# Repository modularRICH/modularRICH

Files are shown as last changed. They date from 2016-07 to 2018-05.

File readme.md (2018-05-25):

# Modular Ring Imaging Cherenkov Particle Identification Detector
The modular aerogel RICH is designed for hadron identification covering a momentum range of 3-10 GeV/c. Identification of the hadrons in the final state is needed for understanding how different quark flavors contribute to the properties of hadrons, and reliable identification of the scattered electron is important for covering kinematics where pion backgrounds are large. This hardware is being prototyped as one of the detectors in the future [Electron-Ion Collider](https://arxiv.org/abs/1212.1701) (EIC), and some of them have recently been tested at Fermilab.

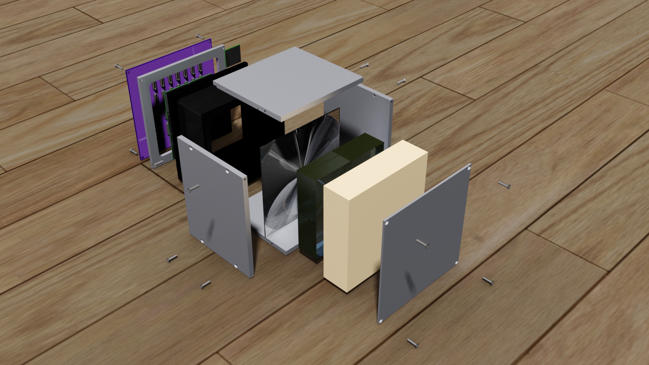
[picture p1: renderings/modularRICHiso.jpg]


## Theory
Aerogel, silicon dioxide and air has a very low index of refraction, and is being used as a radiator material. When high energy charged particles, the remnants of collisions in the interaction region, pass through the aerogel, their phase velocity exceeds that of the speed of light in the medium. They release some of this energy in the form of cones of light, emanating from the collision point. The particle continues through, generally passing through the rest of the instrument.

This cone of light then passes through the Fresnel lens where it is focused towards the center of the sensor plane, which lies at the focal length. The mirrors provide light from particles coming in at an angle to still be focused on the sensor. The ring pattern that emerges can be able to differentiate pions and kaons, and their respective energies.

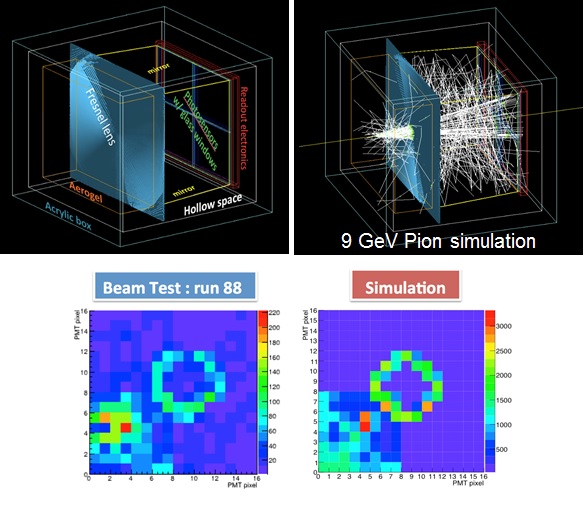
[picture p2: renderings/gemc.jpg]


## Hardware
The detector consists of a optical cavity that is sealed to be light tight, and a interface board for electronics, that allows the heat to be dissipated. The modules in the prototype are designed to be easily removable allowing runs with and without the mirror, aerogel, and/or lens and servicing. The list follows the beam path.

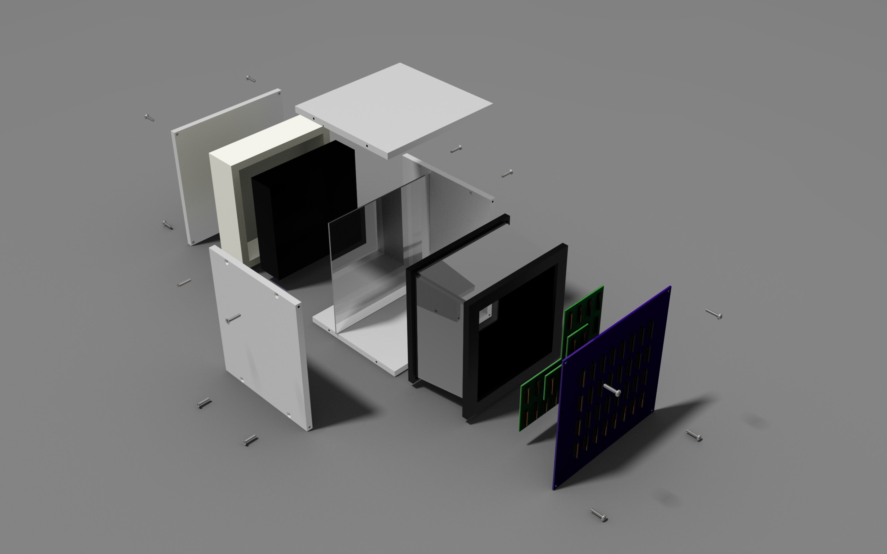
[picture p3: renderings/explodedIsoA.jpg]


### Frame
The frame is made from 1/4" aluminium and assembled with 4-40 screws. The rabet joints form blind corners, which can be further sealed with RTV or aluminium tape. The metal sides are much better at blocking light than the acrylic used in the earlier prototype that was less opaque than expected. The interior and exterior are anodized black to prevent internal light bounces to blur the image. The top and bottom sections are grooved allowing precise placements of the inner modules, and prevent them from shifting. Any of the five panels can be easily removed with only four screws, making servicing quick.

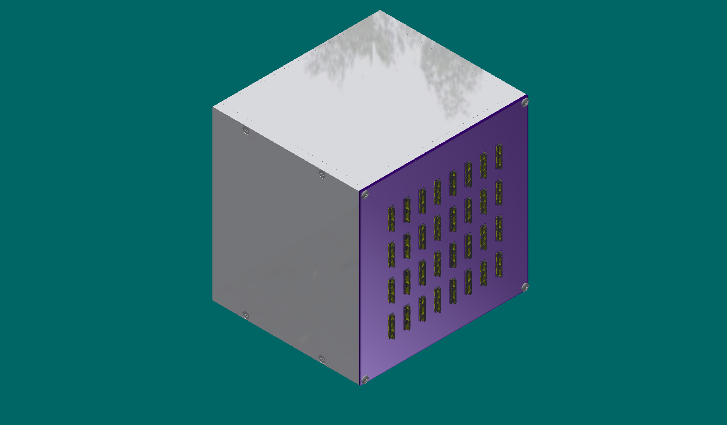
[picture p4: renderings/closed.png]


### Aerogel
Silica aerogel has been used for decades in threshold Cherenkov counters for high energy physics. The aerogel block used is 110mm x 110mm x 33mm and housed in a foam block. The material is extremely fragile and fractures irregular based on formation impurities. It has a index of refraction around 1.01-1.10 depending on its quality, and may have a slight blue hue or be completely clear.

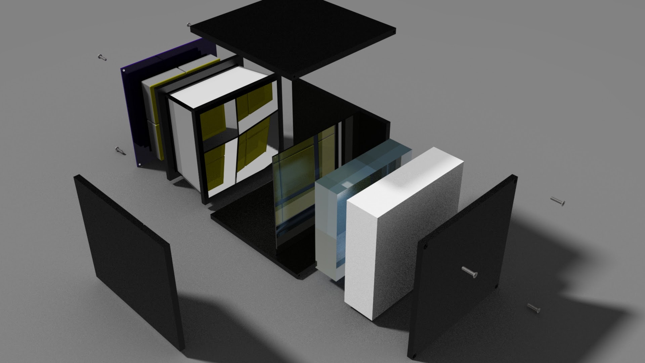
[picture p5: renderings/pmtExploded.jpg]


### Fresnel Lens
The fresnel lens used in this design is manufactured by Edmond Optics [part#](http://www.edmundoptics.com/optics/optical-lenses/fresnel-lenses/fresnel-lenses) and has the critical dimension of 6in for the focal length. It is cut smaller than its original 6.7in x 6.7in (fix size) on order to fit the box, and has an effective diameter of 6in. Due to those two factors, the edges of the lens do not contain any grooves, and are ineffective at refracting light. By switching to a longer focal length lens than our previous prototype (3in), we are able to get a larger ring size, and therefore increse the identification power. 

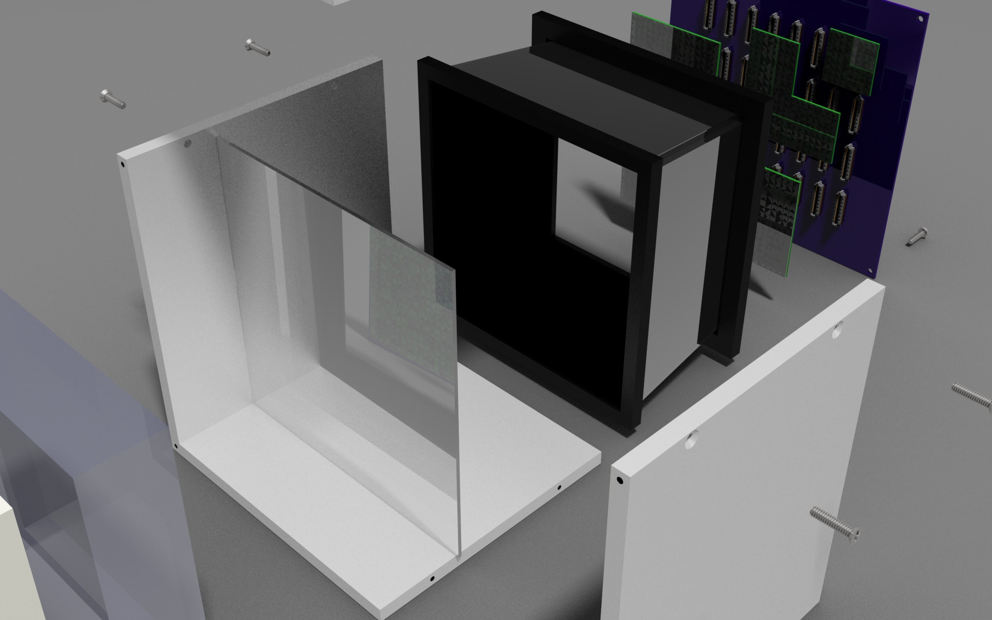
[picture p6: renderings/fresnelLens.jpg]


### Mirror
The mirrors used are front surface mirrors that are trapezoidal. Four of these assemble into a pyramid with a wall inclination of 5 degrees. They are scientific grade 6mm glass mirrors purchased from [fsm](http://firstsurfacemirror.com/trapezoid-first-surface-mirror/) who provides cutting to size. They are glued into acrylic holders that also act as spacers providing exactly the focal length between the lens, and the sensor.



### Sensor
The sensor is the method of readout for determining ring size. As the number of photons produced is low, and event rate is high, the option used in the first prototype was a anode photomultiplier tube (pmt) array [H12700](https://www.hamamatsu.com/resources/pdf/etd/H12700_TPMH1348E.pdf) a 8x8 pixel (6mm x 6mm pixel size) pmt array. A new option of using MPPC arrays is being considered as a smaller pixel size (3mm x 3mm is required for energy range differentiation). Readout methods still are not finialized therfore the mounting is left undesigned to be finished when the electroincs contraints have been set.

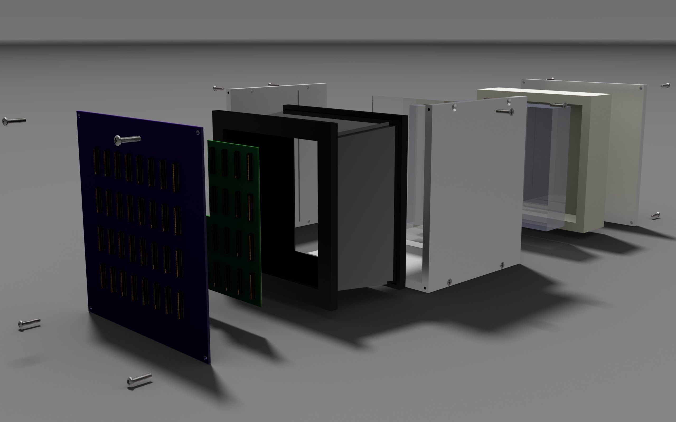
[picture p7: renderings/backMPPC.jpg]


#### MPPC
3mm x 3mm pixel size in a 8x8 array is being considered with 16 modules, meaning 1024 channels being required to act as the sensor plane. Each 8x8 module connects to a backplane that breaks the electrical signals out, allowing electronics to be mounted on the back. 

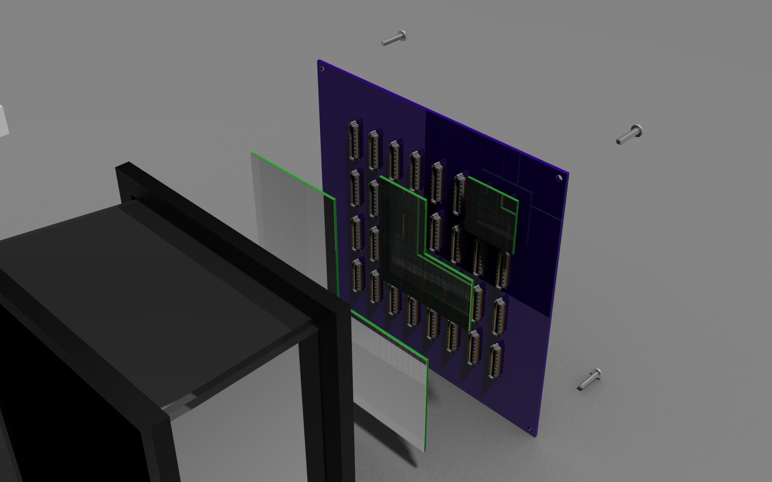
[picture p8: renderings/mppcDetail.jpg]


#### PMT
A 16x16 PMT array with a 3mm x 3mm pixel size is another option. This yields the same coverage area, and the same number of signals, but presents a thicker profile as the dynodes in a PMT require separation. The contacts of this sensor are also broken out through the PCB.

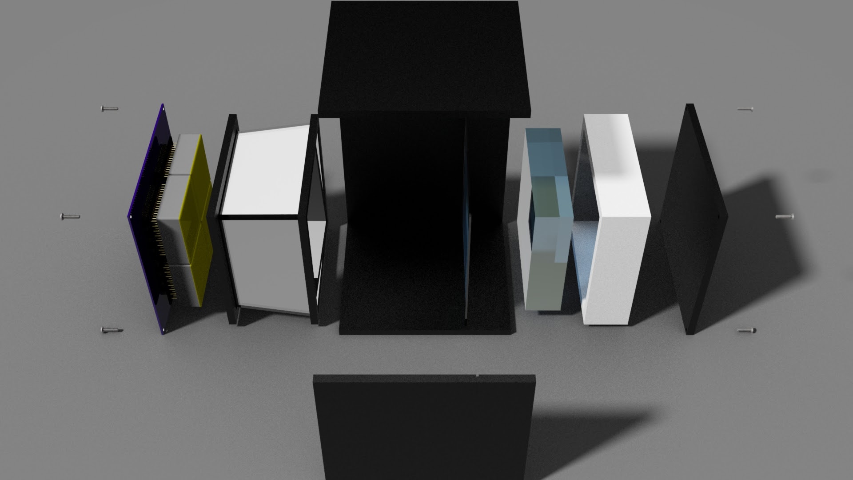
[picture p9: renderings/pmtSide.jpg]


[backMPPC]: renderings/backMPPC.jpg "View of Back of Board"
[closed]: renderings/closed.png "View of Back of Board"
[explodedIsoA]: renderings/explodedIsoA.jpg "View of Back of Board"
[fresnelLens]: renderings/fresnelLens.jpg "Detail view of Fresnel Lens"
[modularRICHiso]: renderings/modularRICHiso.jpg "View of Back of Board"
[gemc]: renderings/gemc.jpg "View of Back of Board"
[mppcDetail]: renderings/mppcDetail.jpg "View of Back of Board"
[pmtExploded]: renderings/pmtExploded.jpg "View of Back of Board"
[pmtIsoB]: renderings/pmtIsoB.jpg "View of Back of Board"
[pmtSide]: renderings/pmtSide.jpg "View of Back of Board"

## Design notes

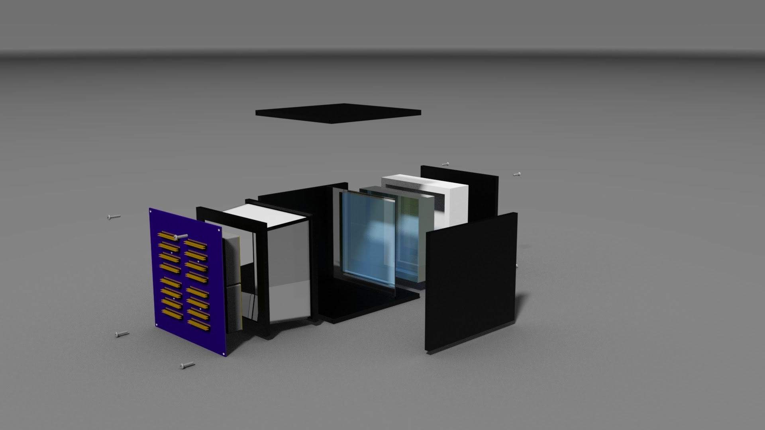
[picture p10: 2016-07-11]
renderings/pmtIsoB.jpg

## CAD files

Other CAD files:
modularRICH.dwg
aerogel.ipt
aerogelHolder.ipt
dependency/13361-30xxAE-08/13360-30xx-VE/13360-30xxVE.ipt
dependency/13361-30xxAE-08/13361-30xxAE-08.iam
dependency/13361-30xxAE-08/ST4-40-1.00-L-D-P-TR/ST4-40-1_00-L-D-P-TR.iam
dependency/13361-30xxAE-08/ST4-40-1.00-L-D-P-TR/ST4-40-1_00-L-D-P-TR_terminal.ipt
dependency/13361-30xxAE-08/ST4-40-1.00-L-D-P-TR/ST4-40-1_00-L-D_pin.ipt
dependency/13361-30xxAE-08/backerBoardConnector.iam
dependency/13361-30xxAE-08/backerConnectorMount.ipt
detector/detectorArray.iam
frame/bottom.ipt
frame/frame.iam
frame/front.ipt
frame/frontClamp.ipt
frame/leftSide.ipt
frame/rightSide.ipt
frame/top.ipt
fresnelLens.ipt
hardware/4-40x0.5in-flat.ipt
hardware/4-40x0.5in-pan.ipt
hardware/no4washer.ipt
mirror/mirrorBackFrame.ipt
mirror/mirrorFrontFrame.ipt
mirror/mirrorHolder.iam
mirror/mirrorSides.ipt
modularRICH.iam

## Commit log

2015-10-13 Base files done
    [aerogelBlock.ipt, back.ipt, frame.iam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]
2015-10-13 Mirror and fresnel
    [mirror.iam, mirror.ipt, modularRICH.iam]
2015-10-14 New mirror desigin
    [aerogelBlock.ipt, back.ipt, frame.iam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]
2015-10-14 New mirror desigin files
    [mirrorSides.ipt, mirrorSupport.ipt, mirrorTopBottom.ipt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]
2015-10-14 Enclosure is assembeled
    [aerogelBlock.ipt, back.ipt, frame.iam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]
2015-10-14 Added showcase Project
    [aerogelBlock.ipt, frame.iam, mirrorSupport.ipt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]
2015-10-20 Rebuilt mirror and housing, water proof
    [0x0.5flatPhilips.ipt, 0x0.625flatPhilips.ipt, aerogelBlock.ipt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]
2015-10-21 Added sensor, larger opening
    [H12700A.iam, H12700A.ipt, aerogelBlock.ipt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]
2015-10-23 Removed O-Rings 3cm aerogel, larger screws
    [0x0.5flatPhilips.ipt, 0x0.625flatPhilips.ipt, aerogelBlock.ipt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]
2015-10-23 Drawings added
    [back.iam, back.ipt, frame.iam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]
2015-10-27 Top opening, parts have movable frames
    [4-40x0.325in.ipt, 4-40x0.5in.ipt, H12700A.iam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]
2016-03-08 Backpane Changed
    [0.25inSpacer.ipt, 2inPvcElbow.ipt, 2x16IDC.ipt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]
2016-03-15 Frame kind of moved out
    [H12700ASuppourt.iam, angleBracket.iam, back.ipt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]
2016-03-15 Deleted a bunch of files
    [0.25inSpacer.ipt, 2inPvcElbow.ipt, 2x16IDC.ipt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]
2016-03-15 Removed top level backplane
    [frame.iam, modularRICH.iam]
2016-04-01 Preperaing for cleanup.
    [mirrorHolder.iam, mirrorSides.ipt]
2016-04-02 Rebuilt Modular RICH using submodules and reorganised directory structure
    [2x18header2mm.ipt, 4-40x0.325in.ipt, 4-40x0.5in.ipt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]
2016-06-05 Starting protoype of new design. First modifications after beamtest
    [4-40x0.325in.ipt, 4-40x0.5in-flat.ipt, 4-40x0.5in-pan.ipt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]
2016-06-07 Aluminium construction, new pcb backplane with MPPC array
    [13360-30xxVE.ipt, 13361-30xxAE-08.iam, 2x18header2mm.ipt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]
2016-06-16 Added groves
    [aerogel.ipt, aerogelHolder.ipt, bottom.ipt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]
2016-06-17 Spacer resides with backplane
    [13360-30xxVE.ipt, 13361-30xxAE-08.iam, ST4-40-1_00-L-D-P-TR.iam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]
2016-06-17 Fixed Drawing
    [back.ipt, frame.iam, front.ipt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]
2016-06-17 Removed connector
    [lvConnector.ipt, shv.ipt]
2016-07-09 Updated submodule to http, imported files that were lost
    [13360-30xxVE.ipt, 13361-30xxAE-08.iam, ST4-40-1_00-L-D-P-TR.iam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]
2016-08-19 Made length longer, using 6 in fresnel
    [modularRICH.iam, modularRICH.xlsx]
2017-01-11 6in focal length, prep for drawings
    [4-40x0.5in-flat.ipt, aerogel.ipt, aerogelHolder.ipt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]
2017-01-11 Drawings made
    [aerogel.ipt, aerogelHolder.ipt, bottom.ipt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]
2017-02-16 Mirror angle 2.5deg, front clamp added,larger aerogel area, depth 8in
    [aerogel.ipt, aerogelHolder.ipt, bottom.ipt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]
2017-03-28 Added four screws on front, incresed fresnel groove width to 70 thou
    [aerogel.ipt, aerogelHolder.ipt, bottom.ipt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]
2018-05-25 removed old backplane
    [4-40x0.5in-flat.ipt, aerogel.ipt, aerogelHolder.ipt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]
